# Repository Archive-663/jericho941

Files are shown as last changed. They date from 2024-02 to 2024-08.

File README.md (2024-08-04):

# Lot no. 014 | Accessories for the IMI Jericho 941 (Pre-2007)

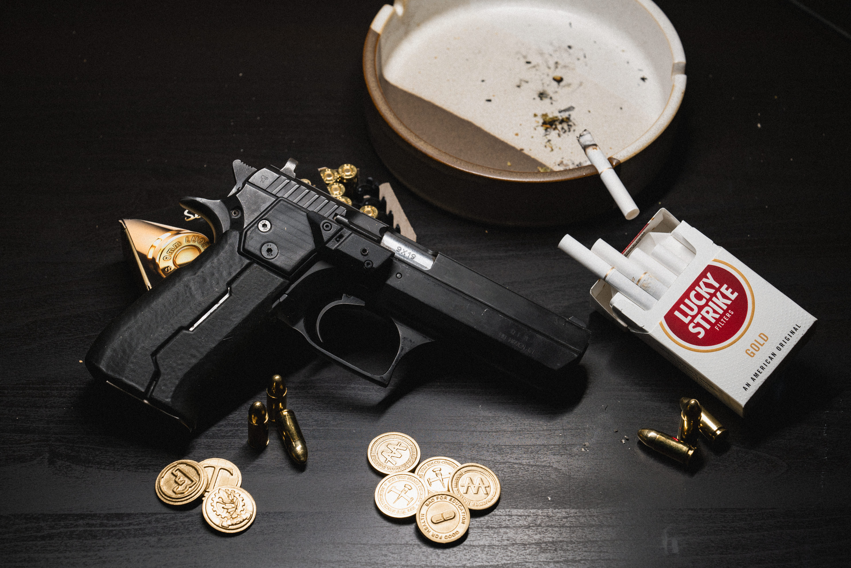
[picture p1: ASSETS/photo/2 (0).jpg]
samplePhoto001


### In this repository:
- [Jericho 941 Grips](https://github.com/Archive-663/jericho941/tree/main/Grips)
- [Jericho 941 Cowboy Bebop Grips](https://github.com/Archive-663/jericho941/tree/main/CowboyBebopGrips)
- [Jericho 941 Stand](https://github.com/Archive-663/jericho941/tree/main/Stand)
- [Jericho 941 Frame](https://github.com/Archive-663/jericho941/tree/main/Frame)

### Background Story:
I picked up a surplus Jericho 941 a while ago with the intention of building out a set of functional Cowboy Bebop laser sight grips. I've finished them, but I'm looking to see if I can partner with someone to actually produce them. The plan is to produce them or upload them here if I can't find anyone in a reasonable amount of time. That said, I wanted to display my Jericho and have a set of back up stock grips. That's what's here in thie archive. Just some grips and a stand. Coming soon will be a simple speedloader/unloader and possibly the reverse engineered frame and raw scan data from my Jericho.

### Help support Archive 663 with a dontation or monthly sub



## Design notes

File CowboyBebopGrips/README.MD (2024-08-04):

# Jericho 941 (pre-2007) Cowboy Bebop Grips

Jericho941Grips000
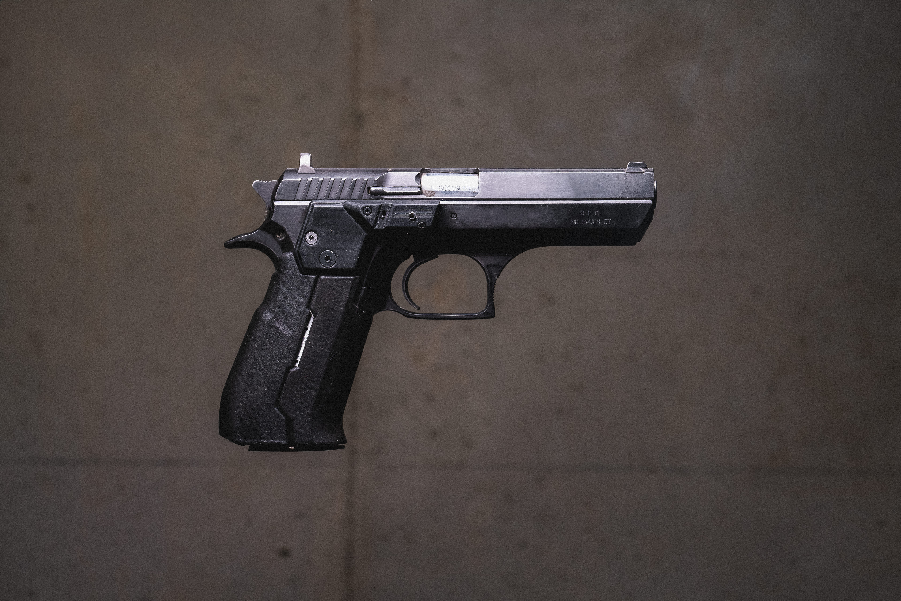
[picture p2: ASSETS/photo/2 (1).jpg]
Jericho941Grips001

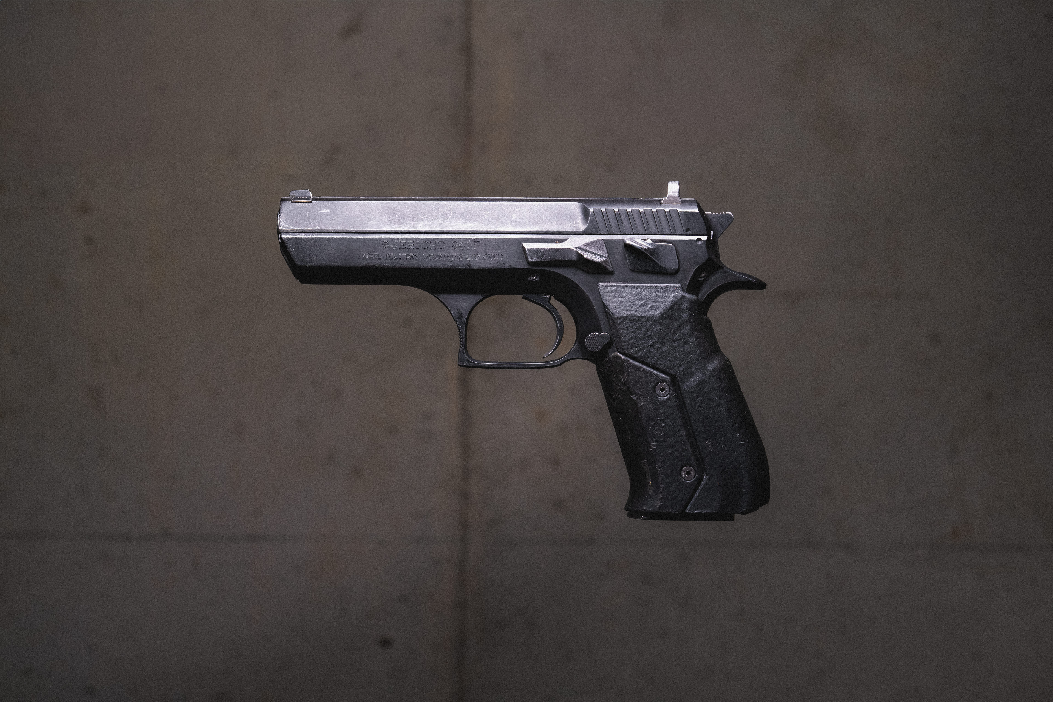
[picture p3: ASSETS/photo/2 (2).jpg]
Jericho941Grips002

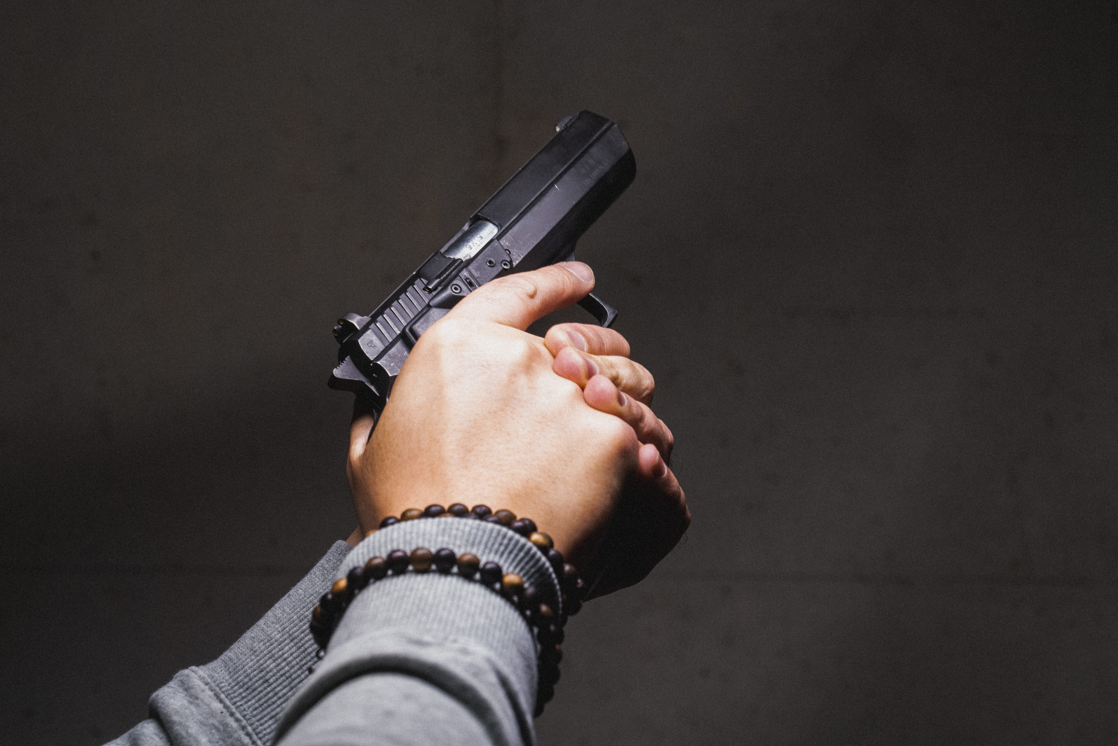
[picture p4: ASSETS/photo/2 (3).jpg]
Jericho941Grips003

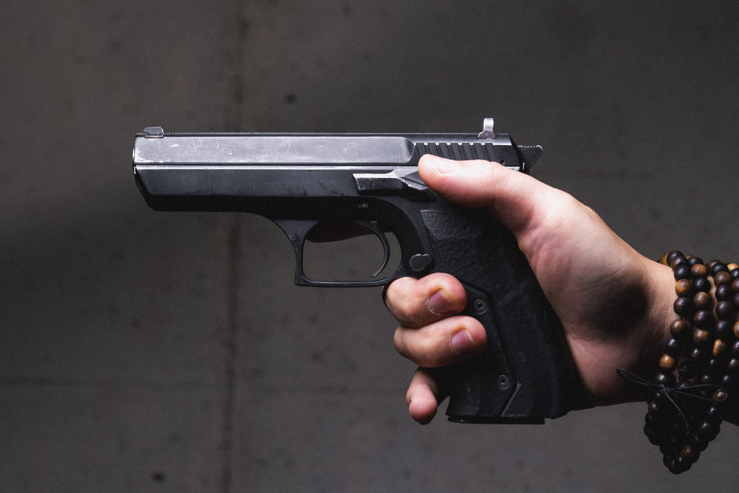
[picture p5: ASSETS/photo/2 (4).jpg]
Jericho941Grips004

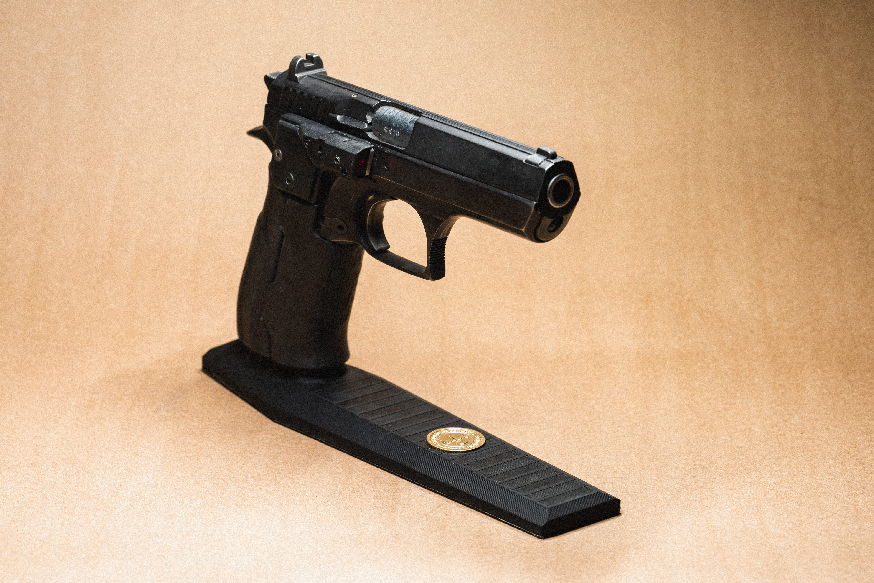
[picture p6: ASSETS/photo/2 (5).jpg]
Jericho941Grips005

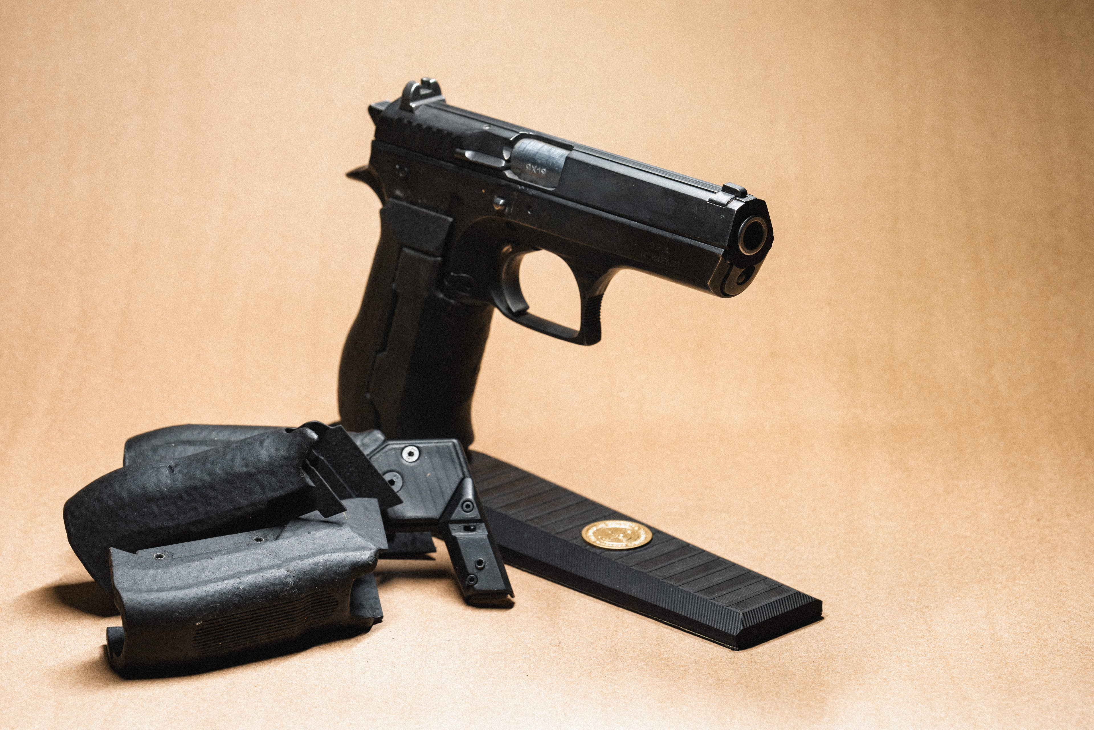
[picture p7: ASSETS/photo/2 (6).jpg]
Jericho941Grips006

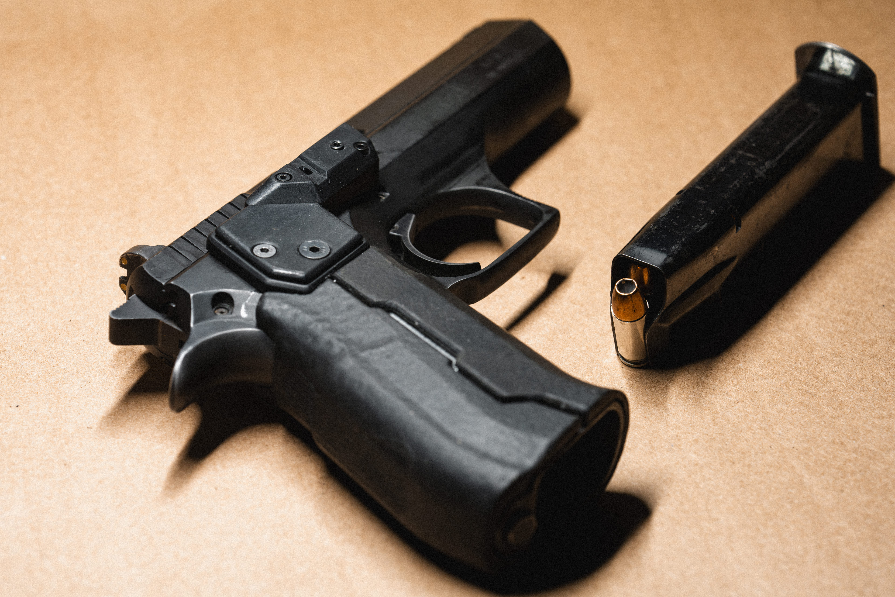
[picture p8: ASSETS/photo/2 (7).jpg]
Jericho941Grips007

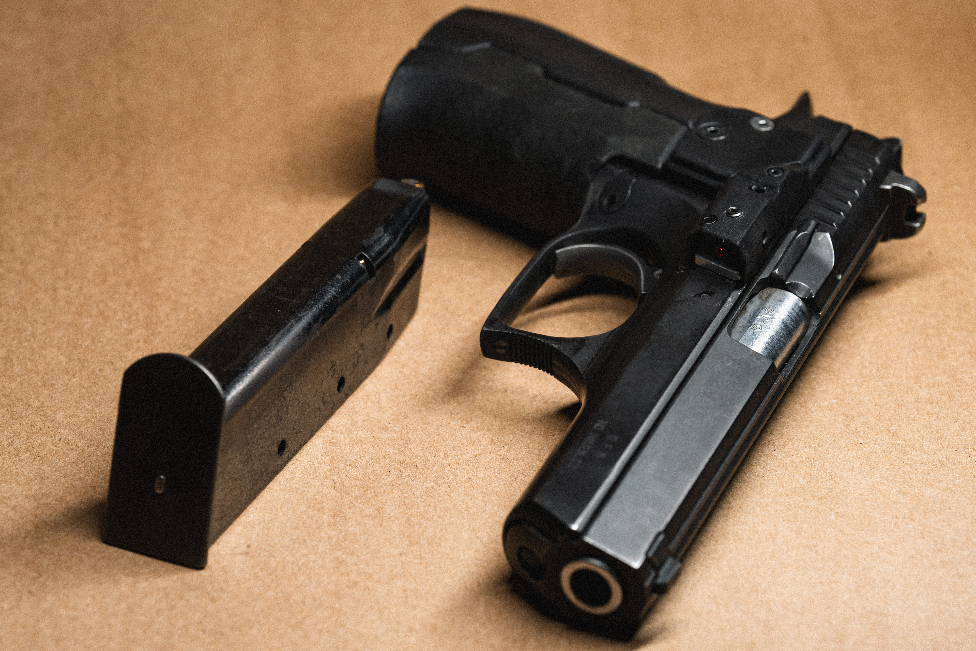
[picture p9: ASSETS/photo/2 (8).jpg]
Jericho941Grips008


A collection of Grips to improve the handling for the Jericho 941 (pre-2007)

### Features:
- Two (2) backstraps
	- Fullsize
	- Midsize
- Laser module with adjustable windage and elevation
	- Powered with one (1) CR2025
- Backstraps with no laser module

### What you'll need:
- A micro file
- M2 Tap
- M3 Tap
- M2 Drill Bit
- M3 Drill Bit
- 2x Prusa Nut
- 2x M2 x 8mm Hex Socket Machine Screw
- 2x M2 x 4mm Countersunk Machine Screw
- 3x M3 x 6mm Countersunk Machine Screw
- 2x M3 x 3mm Set Screw (Grub Screw)
- 1x 3mm x 4mm x 2.5mm Micro Momentary Switch
- <a href="https://www.ebay.com/itm/202655657434" target="_blank">1x 4mm red laser module found here</a>

### Printing suggestion:
- I can only recommend Nylon-like SLA resin or some sort of MJF printing for these grips. You can try FDM printing, but I wasn't happy with the resolution of the finished print. It's possible to print a mold and cast them out of epoxy or urethane for increased strength and impact resistance.
- Follow the printOrientationFile.lys for print orientation. I print with Lychee so I've included a printOrientationFile.STL if you use something else so you can understand how to orient your prints. 
- You will need to have the ...laserPlate.stl file CNC printed. There is no way a 3D printed part could stand the recoil shock.
- You will need to DIY your own positive and negative leads for the battery terminals.

### Post Processing:
- You'll have to sand to fit. There's some room for movement so that you can fit it to your Jericho. You may need to apply some gaffers tape on the underside of the Front or Backstraps to get a firm fit as well.

### Assembling/Installation:
- Check out the ...assembly.STEP files to understand how to assemble your grips and where the screws go to secure the grip.
- To install the frontstrap, you'll have to work the dovetails over the frame to fit.
	- Insert the laserPlate into the backstrap of your choice
	- Secure the laserPlate with the two (2) M2 x 4mm Countersunk Machine Screws
	- Install the Prusa Nuts on the inside of the backstrap
	- Install the backstrap/laserPlate assembly so that the frontstrap dovetails engage with the laserPlate.
	- Secure the grip with the two (2) M3 x 6mm Countersunk Machine Screws
	- Install and secure the positive and negative leads to the Laser mainBody
	- Install and solder the microswitch to the positive and negative leads
	- Install the laser module and solder the negative and positive terminals to the battery terminal leads
	- Install the laser plug
	- Install the two (2) M3 x 3mm Set Screw
	- Install the Laser mainBody
	- Secure the Laser mainBody with the two (2) M2 x 8mm Hex Socket Machine Screws
	- Install the CR2025 battery
	- Install the TPU activation button to the battery cover
	- Install the battery cover
	- Secure with the M3 x 6mm Countersunk Machine Screw

### Warning:
These are still 3d printed grips. If you choose to print them and live fire with them, please do so at your own risk. 

### Help support Archive 663 with a dontation or monthly sub



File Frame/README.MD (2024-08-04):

# Jericho 941 (pre-2007) Frame

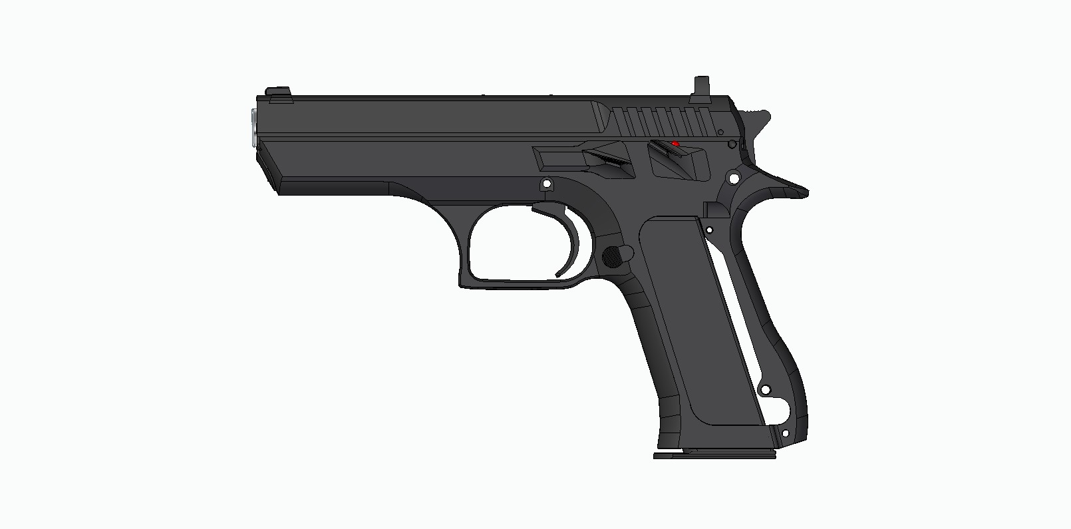
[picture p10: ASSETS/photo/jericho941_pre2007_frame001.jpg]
Jericho941frame001

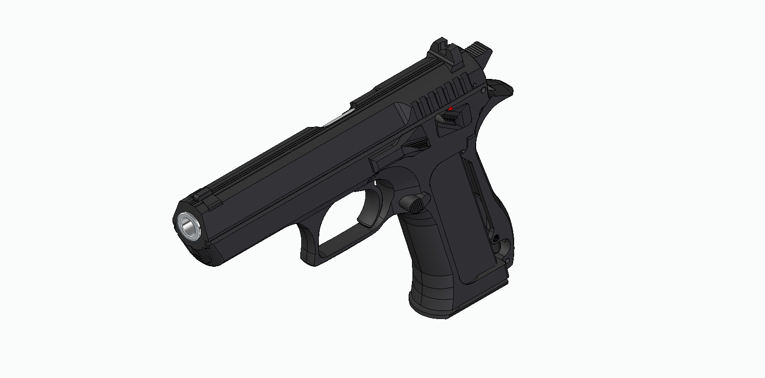
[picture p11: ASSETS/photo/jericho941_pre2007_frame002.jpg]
Jericho941frame002


A reversed engineered Jericho 941 (pre-2007) frame

### Features:
- Partially complete reverse engineered frame for you to build accessories for the Jericho 941

### Background Story:
This Jericho frame has been reversed engineered from a 3d scan from my personal Jericho. There may be some dimensions that are off because of age, wear, and design inference, but it is as accurate as I can have it. 

### Help support Archive 663 with a dontation or monthly sub



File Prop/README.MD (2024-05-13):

# Jericho 941 (pre-2007) Cowboy Bebop Prop

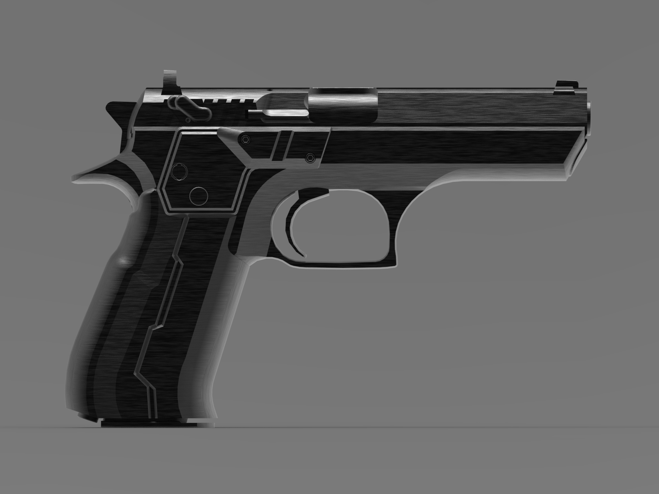
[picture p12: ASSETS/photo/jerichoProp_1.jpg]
Jericho941Prop1

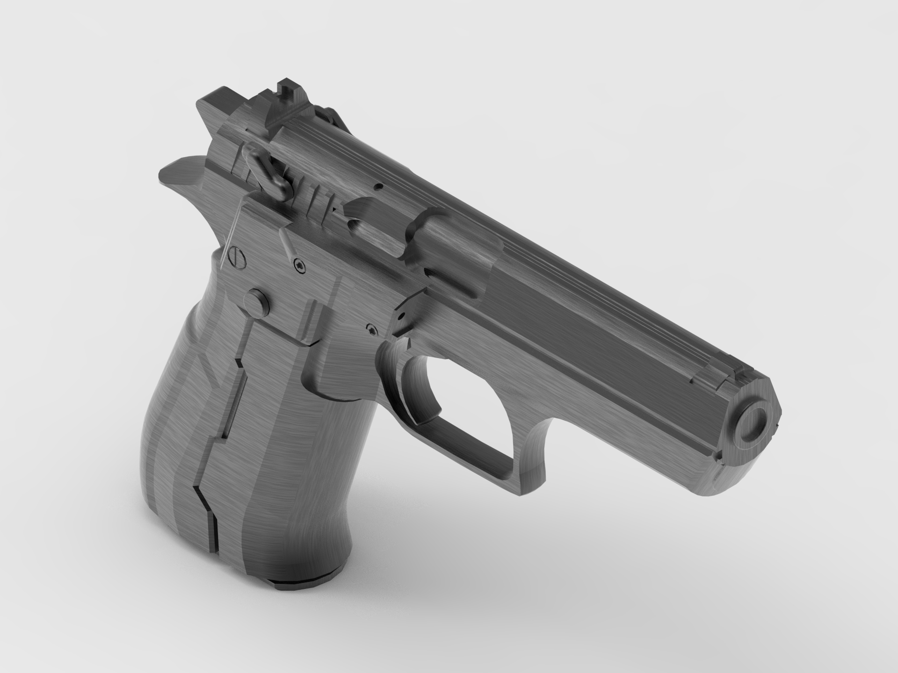
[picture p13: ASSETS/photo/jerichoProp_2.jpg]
Jericho941Prop2


### Features:
- Frame based on a Jericho 941F

### Coming soon:
- Spike Spiegel's laser grip from Cowboy Bebop. 

### What you'll need:
- a micro file
- adhesive

### Printing suggestion:
- Included are a full body and split body for printing however you want. Probably a higher success ratio with the split halves. 

### Post Processing:
- Coming soon...

### Help support Archive 663 with a dontation or monthly sub



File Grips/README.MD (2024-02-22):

# Jericho 941 (pre-2007) Grips

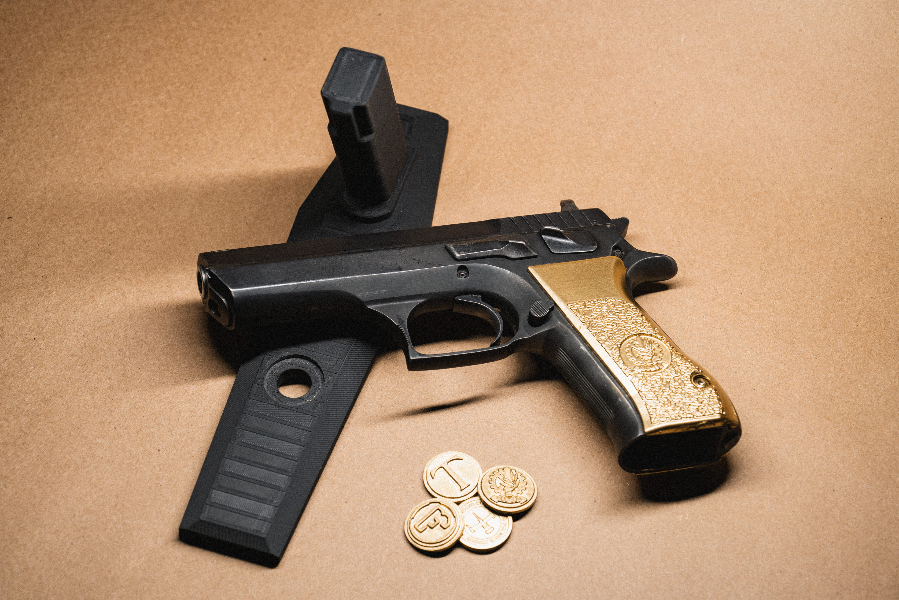
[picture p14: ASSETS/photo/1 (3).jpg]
Jericho941Grips003

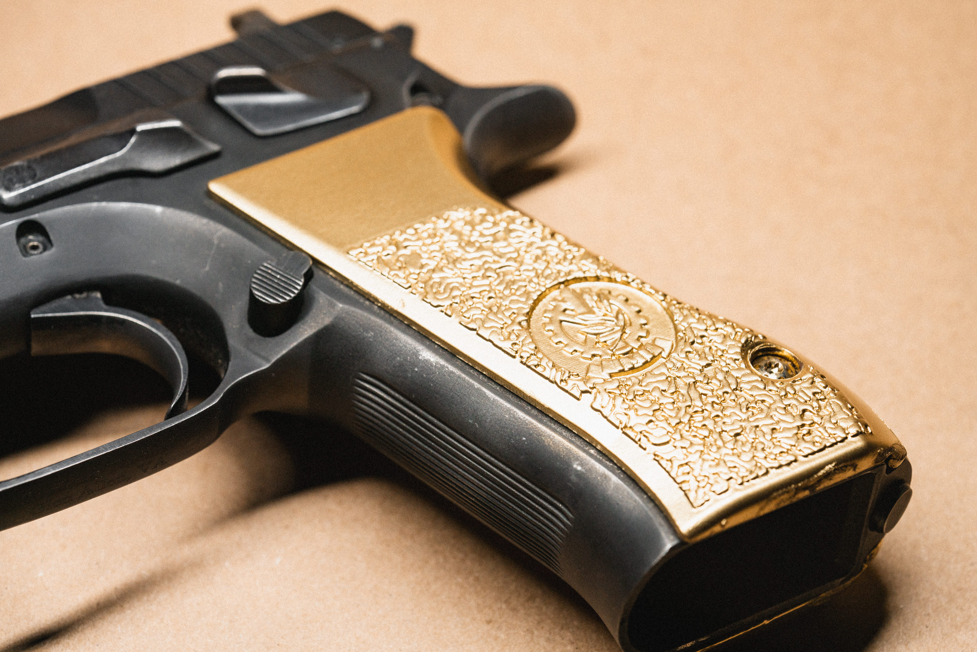
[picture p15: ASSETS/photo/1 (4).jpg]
Jericho941Grips004

Jericho941Grips006

A collection of Grips to improve the handling for the Jericho 941 (pre-2007)

### Features:
- Original IMI logo
- Blank grip panels for custom grip texture
- Standard texture grip panels
- .afdesign and .svg file for cutting your own texture

### Coming soon:
- Spike Spiegel's laser grip from Cowboy Bebop. 

### What you'll need:
- a micro file

### Printing suggestion:
- I can only recommend Nylon-like SLA resin or some sort of MJF printing for these grips. You can try FDM printing, but I wasn't happy with the resolution of the finished print. It's possible to print a mold and cast them out of epoxy or urethane for increased strength and impact resistance.
- I print the standard grips at a 15 degree tilt with the interior facing the build plate
- Follow the printOrientationFile.lys for print orientation. I print with Lychee so I've included a printOrientationFile.STL if you use something else so you can understand how to orient your prints. 

### Post Processing:
- I left some material on the uppper dovetail or french cleat so that you can get a firm fit on your frame. File it down so that the grip mounts up and doesn't move.

### Designing your own grip texture:
I've included two 2D design files for you to generate your own texture pattern that can be imported into your CAD program as a .dxf file. Generate a texture, cut it from the template, export as a .dxf file, open the .dxf file in your CAD program. From here you can either project and extrude or extrude, line up where you want it, choose the intersect boolean, and then raise the grip texture 0.5mm. 

<a href='https://github.com/Archive-663/jericho941/tree/main/ASSETS/textureTemplate' target='_blank'>textureTemplate_forGit</a>

### Warning:
These are still 3d printed grips. If you choose to print them and live fire with them, please do so at your own risk. 

### Help support Archive 663 with a dontation or monthly sub



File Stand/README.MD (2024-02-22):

# Jericho 941 (pre-2007) Stand

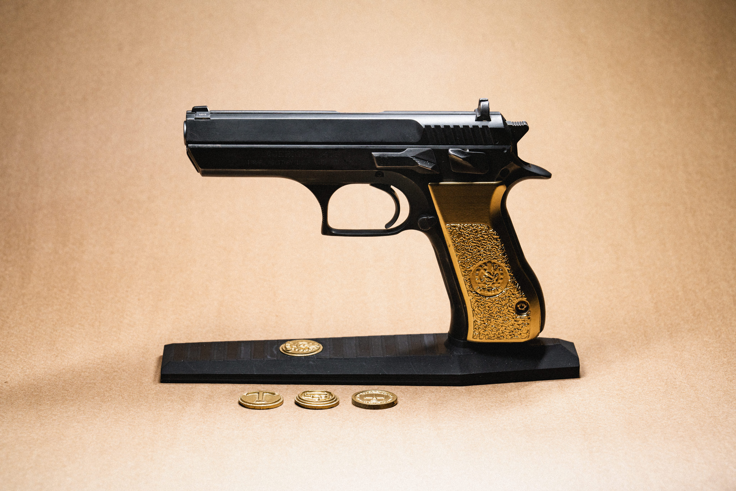
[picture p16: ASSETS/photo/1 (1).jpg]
Jericho941Grips001

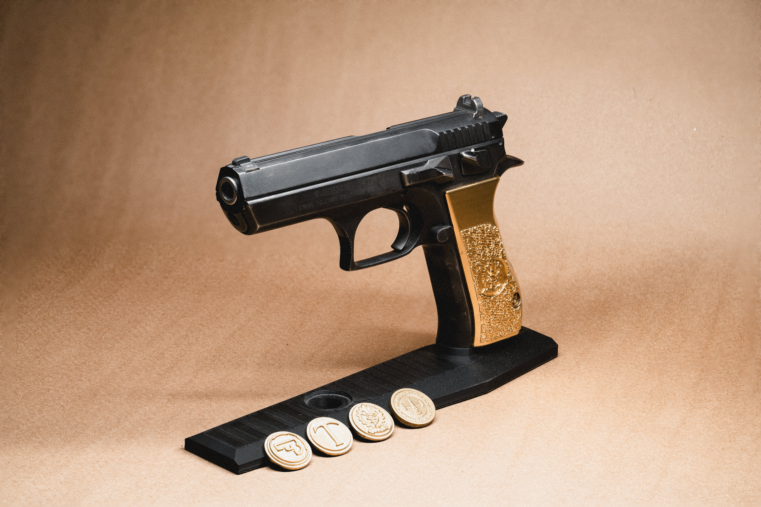
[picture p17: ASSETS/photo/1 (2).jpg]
Jericho941Grips002

Jericho941Grips003

A stand for the Jericho 941 (pre-2007) and any CZ-75 based frame.

### Features:
- Full length of magazine for better alignment
- Logo emblems for CZ, Tanfoglio, IMI, and Cowboy Bebop to identify the manufacturer

### What you'll need:
- 4mm Adhesive backed Rubber Mat

### Printing suggestion:
- Recommended to print stand in ABS, ABS+, or PETG.
- Follow the printOrientationFile.3mf for print orientation. If importing to CURA you can simply import the models and then slice with your settings. In PrusaSlicer it does not carry the information over well from CURA.
- Recommended to print the emblems/coins standing up. Resin selection does not matter. Please view the attached printOrientationfile.lys or .stl for proper orientation.

### Post Processing:
- Nothing much for post processing on the stand. Apply the 4mm adhesive backed rubber mat on the base of the stand and trim excess.
- For the emblems standard resin post processing applies. Paint as necessary.

### Help support Archive 663 with a dontation or monthly sub



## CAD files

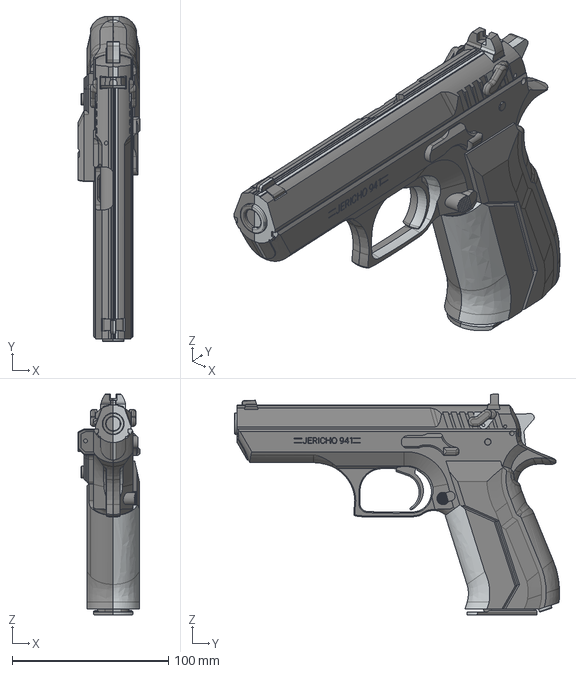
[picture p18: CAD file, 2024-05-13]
Prop/STEP/jericho941_pre2007_prop_bebopLaser_full.stp
40.0 x 208.5 x 141.6 mm

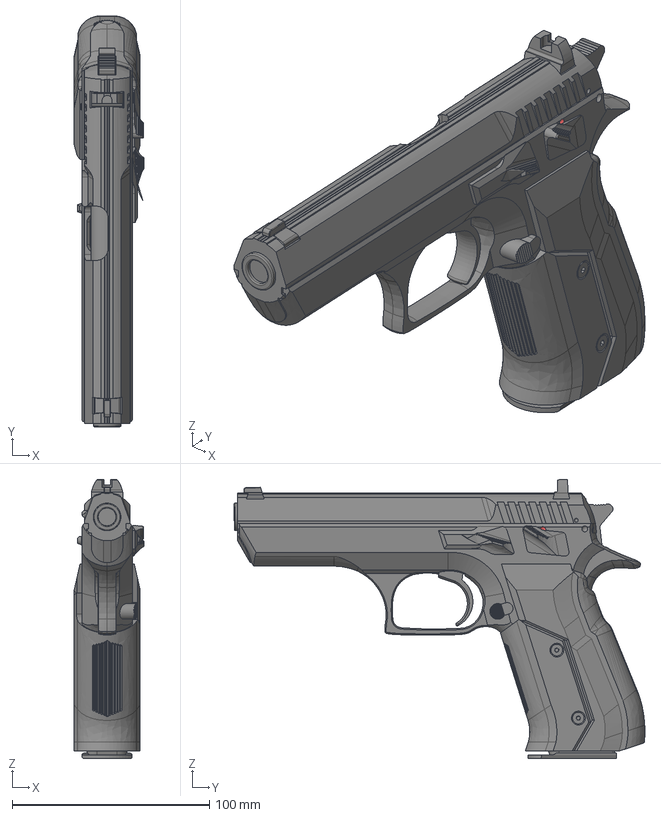
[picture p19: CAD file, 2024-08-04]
CowboyBebopGrips/STEP/jericho941_pre2007_cowboyBebopGrips_fullSize_noLaser_assembly.stp
35.4 x 208.5 x 141.6 mm
jericho941_pre2007_grip_cowboyBebop
M3_prusaNut x 2
jericho941_pre2007_bodyBuck
jericho941_pre2007_grip_cowboyBebop_backstrap_noLaser
M3_countersunkHead_6mm x 2
M2_countersunkHead_4mm x 2

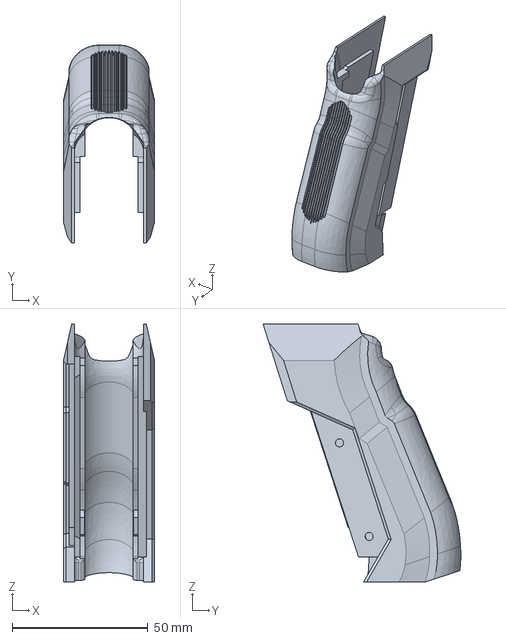
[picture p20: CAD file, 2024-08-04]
CowboyBebopGrips/STEP/jericho941_pre2007_grip_cowboyBebop_backstrap_fullSize_noLaser.stp
33.5 x 72.9 x 95.0 mm

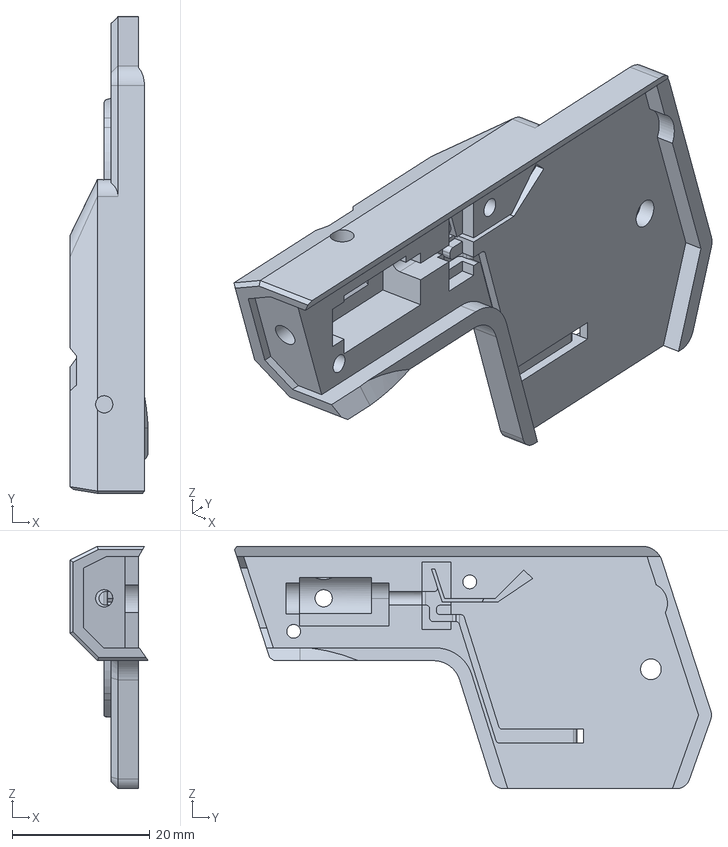
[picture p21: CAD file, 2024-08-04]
CowboyBebopGrips/STEP/jericho941_pre2007_grip_cowboyBebop_laserCover_mainBody_10mm.stp
11.4 x 69.2 x 35.2 mm

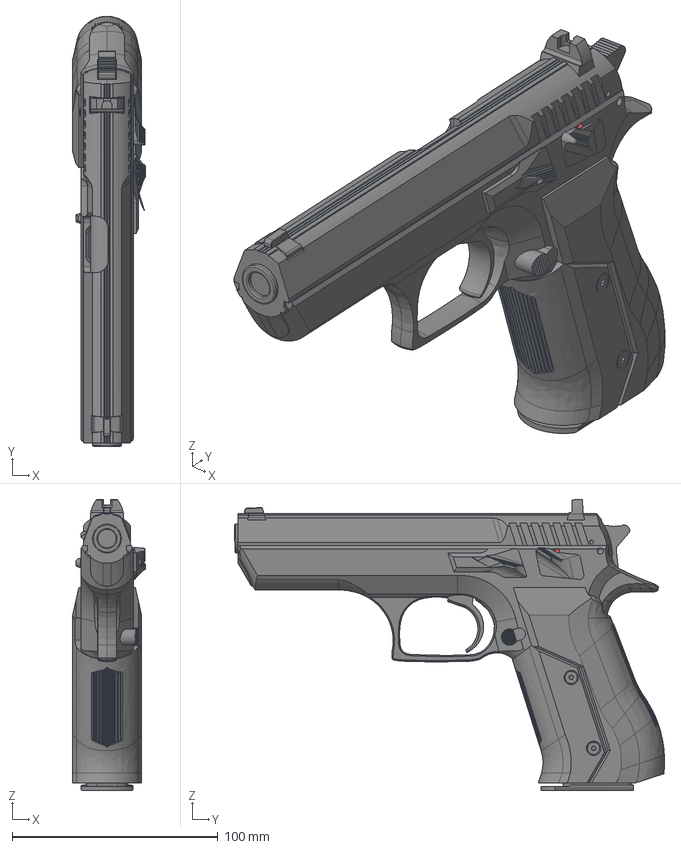
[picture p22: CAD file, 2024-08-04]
CowboyBebopGrips/STEP/jericho941_pre2007_cowboyBebopGrips_midSize_noLaser_assembly.stp
35.4 x 209.1 x 141.6 mm
jericho941_pre2007_grip_cowboyBebop
M3_prusaNut x 2
jericho941_pre2007_bodyBuck
M3_countersunkHead_6mm x 2
jericho941_pre2007_grip_cowboyBebop_backstrap_small_noLaser
M2_countersunkHead_4mm x 2

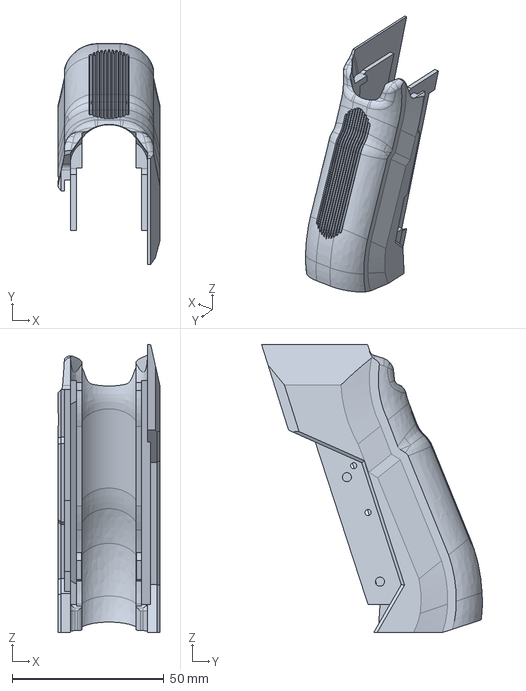
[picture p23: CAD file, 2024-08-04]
CowboyBebopGrips/STEP/jericho941_pre2007_grip_cowboyBebop_backstrap_fullsize.stp
33.5 x 72.9 x 95.0 mm

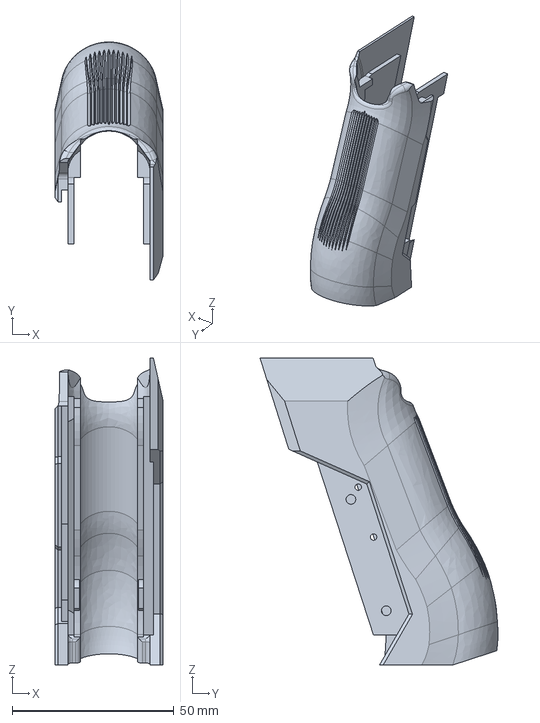
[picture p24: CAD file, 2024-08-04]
CowboyBebopGrips/STEP/jericho941_pre2007_grip_cowboyBebop_backstrap_midSize.stp
33.5 x 73.7 x 95.0 mm

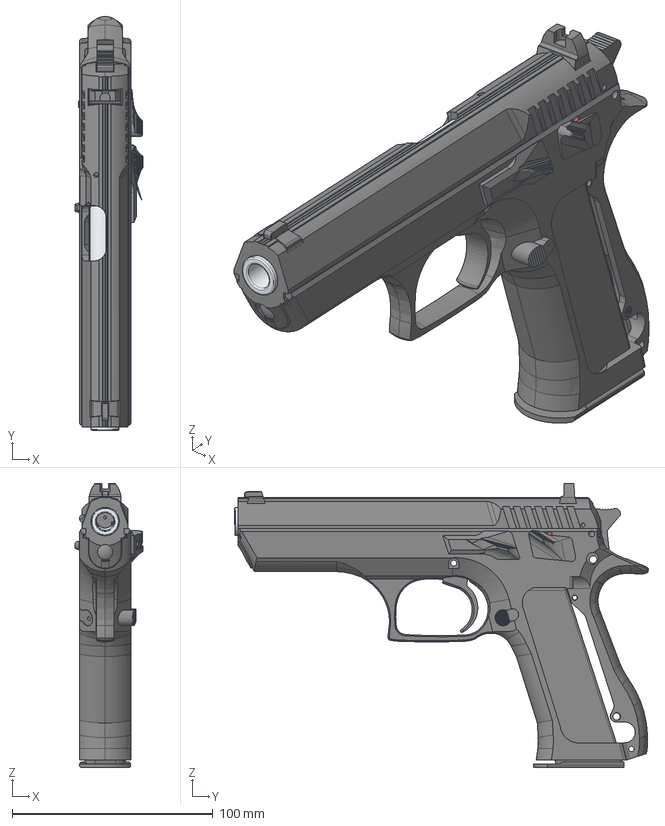
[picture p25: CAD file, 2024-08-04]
Frame/jericho941_pre2007_grips.stp
33.6 x 206.2 x 141.6 mm
jericho941_pre2007_frontSight
jericho941_pre2007_rearSight
jericho941_pre2007_slide
jericho941_pre2007_hammer
jericho941_pre2007_frame
jericho941_pre2007_slideLock
jericho941_pre2007_extractor
jericho941_pre2007_recoilSpringAssembly
jericho941_pre2007_firingPin
jericho941_pre2007_firingPinBlock
jericho941_pre2007_magazineRelease
jericho941_pre2007_trigger
jericho941_pre2007_barrel
jericho941_pre2007_magazineBase
jericho941_pre2007_magazine
jericho941_pre2007_safety

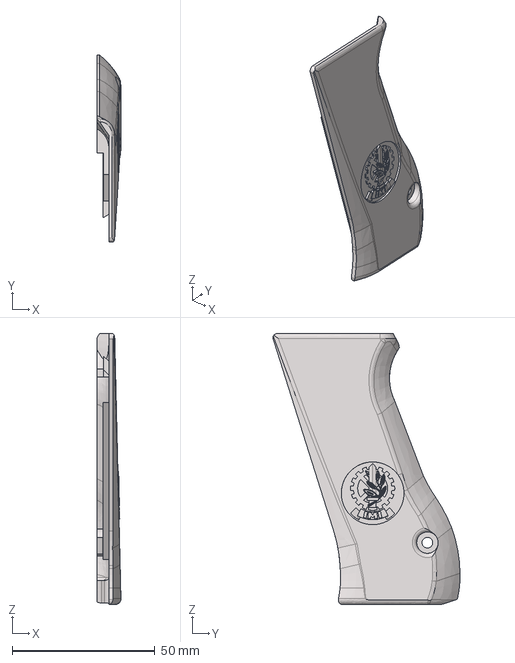
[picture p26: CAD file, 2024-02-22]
Grips/STEP/jericho941_pre2007_gripLeft_stdBlank.stp
8.39 x 65.6 x 95.0 mm

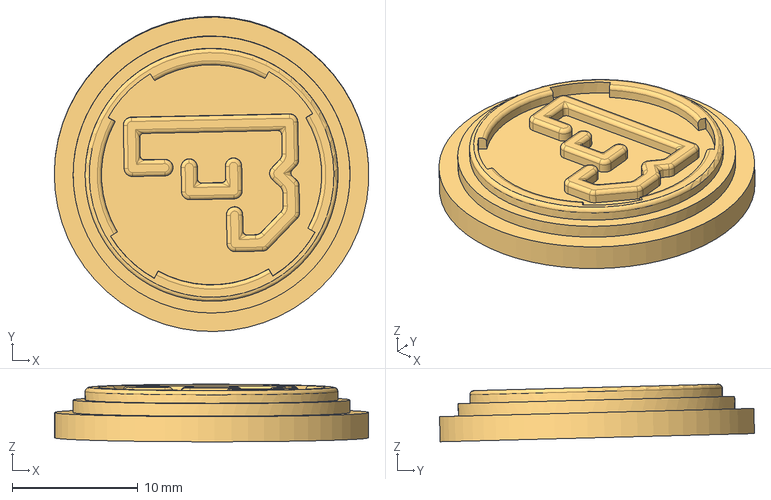
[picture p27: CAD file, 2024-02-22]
Stand/STEP/CZ_standCoin.stp
25.0 x 25.0 x 4.58 mm

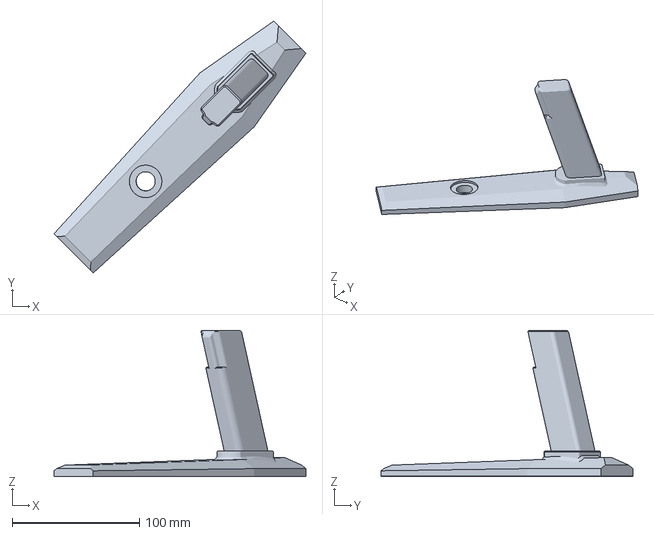
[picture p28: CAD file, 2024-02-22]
Stand/STL/jericho941_pre2007_stand_printOrientationFile.3mf
197.7 x 197.7 x 114.9 mm

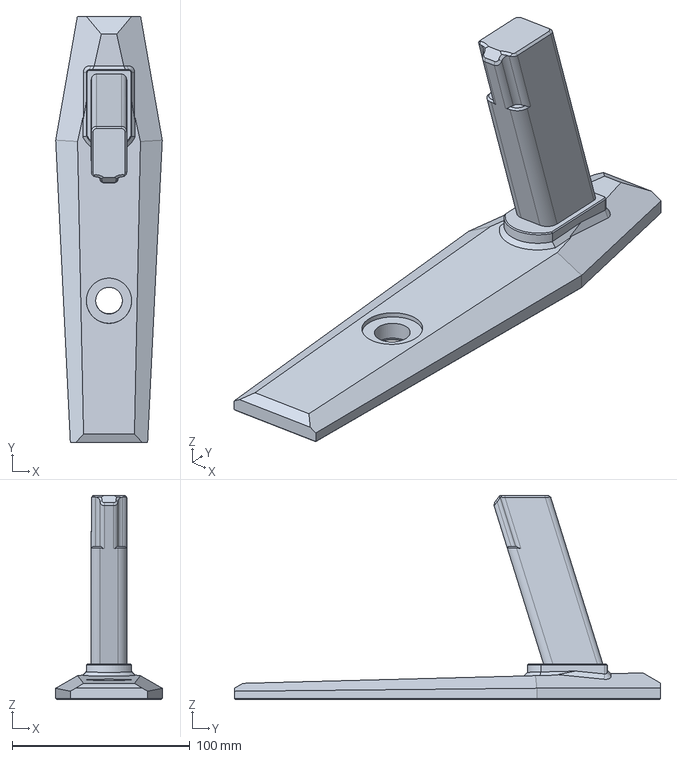
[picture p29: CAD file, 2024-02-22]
Stand/STEP/jericho941_pre2007_stand.stp
60.0 x 240.0 x 114.9 mm

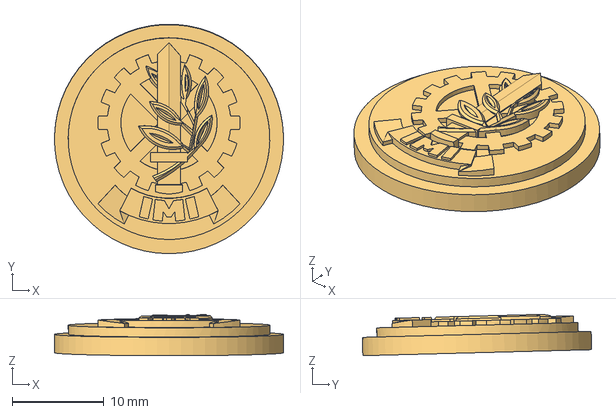
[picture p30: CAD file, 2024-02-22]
Stand/STEP/jericho941_pre2007_standCoin.stp
25.0 x 25.0 x 4.51 mm

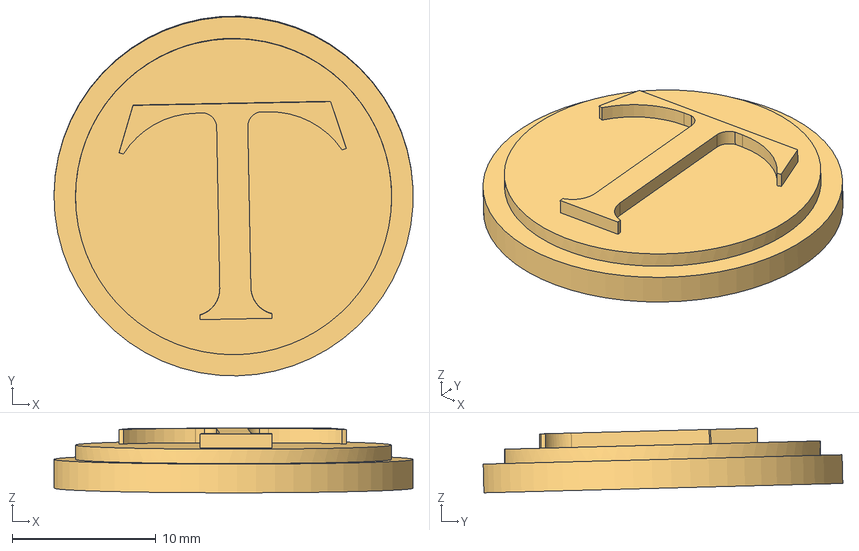
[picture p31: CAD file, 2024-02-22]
Stand/STEP/Tanfoglio_standCoin.stp
25.0 x 25.0 x 4.50 mm

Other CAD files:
Grips/STEP/jericho941_pre2007_gripRight_stdBlank.stp
CowboyBebopGrips/STEP/jericho941_pre2007_grip_cowboyBebop_laserCover_batteryPositiveLead_10mm.stp
Stand/STEP/jericho941_pre2007_standCoin_bebop.stp
CowboyBebopGrips/STEP/jericho941_pre2007_grip_cowboyBebop_laserCover_batteryDoor_10mm.stp
CowboyBebopGrips/STEP/jericho941_pre2007_grip_cowboyBebop_backstrap_midSize_noLaser.stp
CowboyBebopGrips/STEP/jericho941_pre2007_grip_cowboyBebop_frontStrap.stp
CowboyBebopGrips/STEP/jericho941_pre2007_grip_cowboyBebop_laserCover_batteryNegativeLead_10mm.stp
CowboyBebopGrips/STEP/jericho941_pre2007_grip_cowboyBebop_laserCover_buttonTPU_10mm.stp
CowboyBebopGrips/STEP/jericho941_pre2007_grip_cowboyBebop_laserCover_plugTPU_10mm.stp
CowboyBebopGrips/STEP/jericho941_pre2007_grip_cowboyBebop_laserPlate_forCNC.stp
CowboyBebopGrips/STL/jericho941_pre2007_grip_cowboyBebop_frontStrap.stl
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

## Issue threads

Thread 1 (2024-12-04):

Grips with lanyard

maswellM5, 2024-12-04:
Hey -- great project and thanks for sharing.  I thought you might like to have an STL for the Jerichos that have lanyard loops.  I modified your stl until they fit well on my surplus pistol.  Thought this could help others.

[GripswithLanyard.stl.zip](https://github.com/user-attachments/files/18013318/GripswithLanyard.stl.zip)

gmoua663, 2024-12-22:
Ah, it totally slipped my mind that folks would keep the lanyard main spring pin. I replaced mine immediately, but I still have it laying in a box. Appreciate the work, I'll see what I can do on my end.

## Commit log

2024-02-22 Upload Jericho 941
    [CZ_standCoin.stl, CZ_standCoin.stp, Tanfoglio_standCoin.stl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]
2024-05-13 Upload Prop Jericho
    [jericho941_pre2007_prop_bebopLaser_full.stp]
2024-08-04 added the Cowboy Bebop Grips
    [jericho941_pre2007_cowboyBebopGrips_fullSize_noLaser_assembly.stp, jericho941_pre2007_cowboyBebopGrips_midSize_noLaser_assembly.stp, jericho941_pre2007_grip_co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]
